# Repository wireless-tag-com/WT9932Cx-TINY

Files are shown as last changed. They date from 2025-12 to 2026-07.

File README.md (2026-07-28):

# WT9932Cx-TINY Resources

> [!IMPORTANT]
> This repository is no longer actively maintained and is retained as an archive. Board support, examples, and future documentation are now maintained in [WT_BSP](https://github.com/Wireless-TAG-Maker/WT_BSP). The existing contents remain available for historical reference.

[中文](./README_zh.md)

This repository mainly stores resources related to WT9932C2-TINY, WT9932C3-TINY, WT9932C5-TINY, and WT9932C61-TINY.

You can refer to our official documentation:

[WT9932C2-TINY Wiki](https://wiki.wireless-tag.com/docs/en/WT9932C2-TINY/board_features.html)

[WT9932C3-TINY Wiki](https://wiki.wireless-tag.com/docs/en/WT9932C3-TINY/board_features.html)

[WT9932C5-TINY Wiki](https://wiki.wireless-tag.com/docs/en/WT9932C5-TINY/board_features.html)

[WT9932C61-TINY Wiki](https://wiki.wireless-tag.com/docs/en/WT9932C61-TINY/board_features.html)

## Folder Overview

```shell
.
├── hardware # Hardware resources: schematics, BOM, gerber, and component placement files
├── other # User guides, module datasheets, and other documentation
└── software # Software resources
```

1. hardware

The hardware is designed using Lichuang EDA, and the full project will be open-sourced later. Currently, schematics, Gerber files, and other resources are available.

2. other

This folder mainly provides module datasheets, 3D models, CAD dimension drawings, pin definitions, label files, and other resources.

3. software

This folder mainly includes the ESP-IDF blink example, MicroPython firmware, AT firmware, and other software resources.

The environment setup tutorials are available on the online wiki.

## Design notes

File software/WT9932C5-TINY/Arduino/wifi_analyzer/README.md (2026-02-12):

# ESP32-C5 Tiny WiFi Analyzer

## How to Compile and Run

1. Install [Arduino](https://www.arduino.cc/)
2. In `File -> Preferences -> Additional Boards Manager URLs`, add:  
   `https://jihulab.com/esp-mirror/espressif/arduino-esp32/-/raw/gh-pages/package_esp32_index_cn.json`
3. Restart Arduino and install the ESP32 board package  
   > Note: Select the board package authored by `Espressif Systems`
4. Connect the C5 Tiny and select the corresponding COM port in Arduino
5. Open the board selection menu, search for C5, and choose **ESP32C5 Dev Module**
6. Download [Arduino_GFX](https://github.com/moononournation/Arduino_GFX/releases/tag/v1.6.5), extract it, and move it to:  
   `C:\Users\<YourUsername>\Documents\Arduino\libraries`
7. Open `ESP32C5WiFiAnalyzer\ESP32C5WiFiAnalyzer.ino` and install the **U8g2** library in Arduino
8. Compile and upload the firmware to the ESP32C5 Tiny
9. Connect the LCD according to the table below:

   | LCD Pin | ESP32C5 TINY Pin |
   |----------|-------------------|
   | GND      | GND               |
   | VCC      | 3.3V              |
   | SCL      | IO0               |
   | SDA      | IO1               |
   | RES      | IO2               |
   | DC       | IO4               |
   | CS       | IO5               |
   | BLK      | IO6               |

## Result

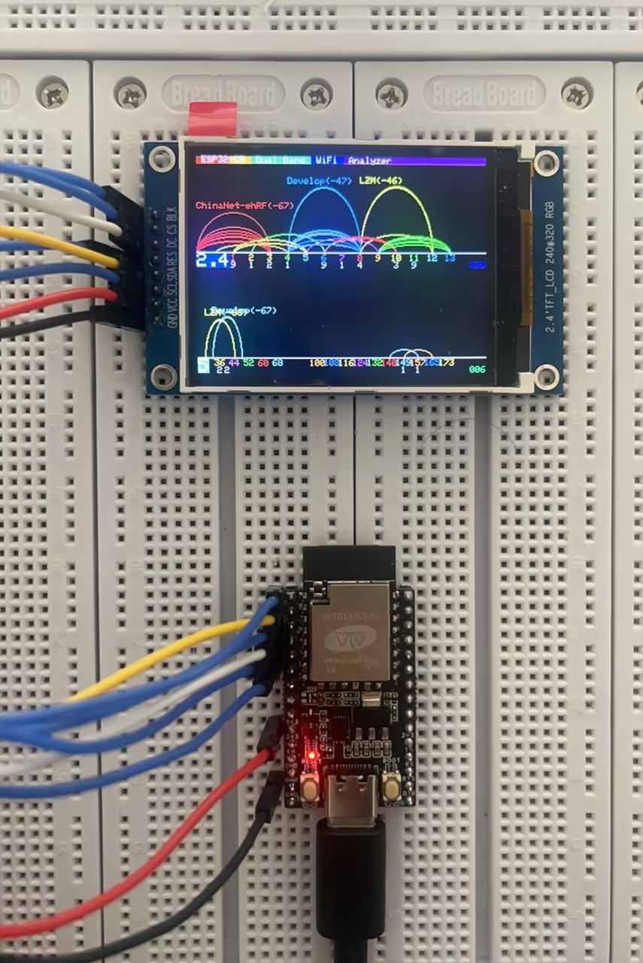
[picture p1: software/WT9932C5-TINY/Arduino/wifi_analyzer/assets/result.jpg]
result


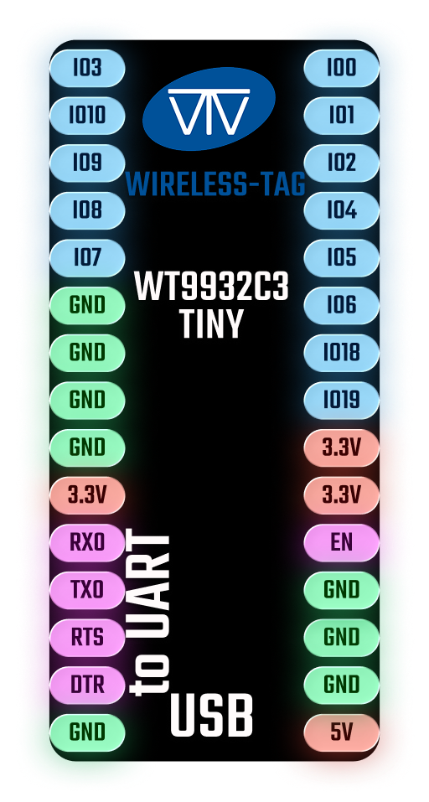
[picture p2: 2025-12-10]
other/WT9932C3-TINY/WT9932C3-TINY.png

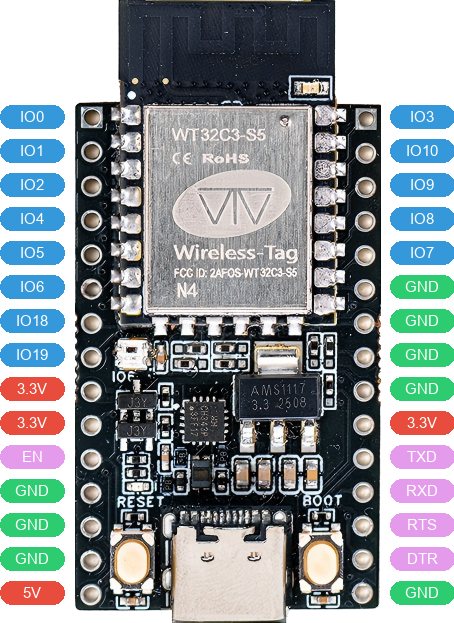
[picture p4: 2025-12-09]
other/WT9932C3-TINY/WT9932C3-TINY_引脚定义_V1.0.png

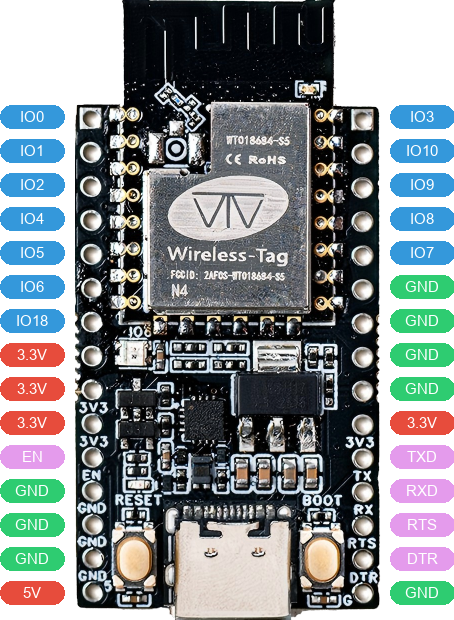
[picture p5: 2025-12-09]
other/WT9932C2-TINY/WT9932C2-TINY_引脚定义_V1.0.png

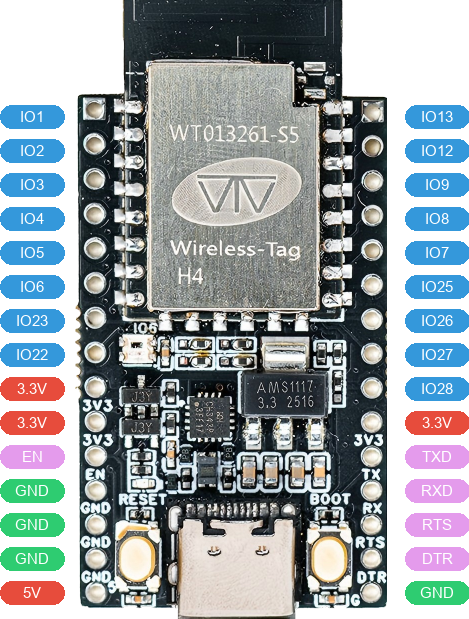
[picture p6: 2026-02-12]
other/WT9932C61-TINY/WT9932C61-TINY_引脚定义_V1.1.png

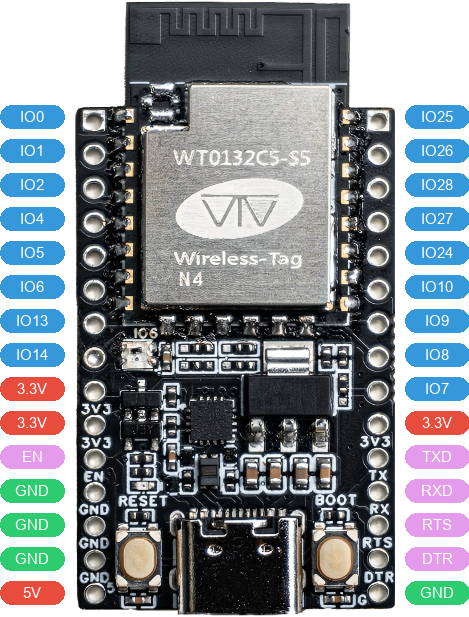
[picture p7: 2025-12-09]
other/WT9932C5-TINY/WT9932C5-TINY_引脚定义_V1.1.png

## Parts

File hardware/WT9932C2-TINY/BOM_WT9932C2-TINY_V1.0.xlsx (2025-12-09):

No. | Quantity | Comment | Designator | Footprint | Value | Manufacturer Part | Manufacturer | Supplier Part | Supplier | Tolerance | Overload Voltage (Max) | Output Voltage
1 | 4 | 100nF | C1,C2,C3,C11 | C0402 | 100nF | CC0402KRX7R7BB104 | YAGEO(国巨) | C60474 | LCSC | ±10%
2 | 3 | 10uF | C13,C15,C16 | C0603 | 10uF | CL10A106KP8NNNC | SAMSUNG(三星) | C19702 | LCSC | ±10%
3 | 1 | 100nF | C14 | C0603 | 100nF | CC0603KRX7R9BB104 | YAGEO(国巨) | C14663 | LCSC | ±10%
4 | 3 | H5VL10B | D1,D2,D3 | SOD-882_L1.0-W0.6-BI |  | H5VL10B | 宏迦橙 | C7420372 | LCSC
5 | 2 | ZX-PZ2.54-1-15PZZ | J1,J2 | HDR-TH_15P-P2.54-V-M |  | ZX-PZ2.54-1-15PZZ | Megastar(兆星) | C7501269 | LCSC
6 | 1 | WS2812B-2020 | J3 | LED-SMD_4P-L2.0-W2.0-TL_WS2812B-2020 |  | WS2812B-2020 | worldsemi | C965555 | LCSC
7 | 1 | TYPE-C 16PIN 2MD(073) | J4 | USB-C-SMD_TYPE-C-6PIN-2MD-073 |  | TYPE-C 16PIN 2MD(073) | SHOU HAN(首韩) | C2765186 | LCSC
8 | 2 | SKRPACE010 | J5,J6 | KEY-SMD_4P-L4.2-W3.2-P2.20-LS4.6 |  | SKRPACE010 | ALPSALPINE(阿尔卑斯阿尔派) | C139797 | LCSC
9 | 1 | SDCW2012C-2-900TF | L1 | FILTER-SMD_4P-L2.0-W1.3-BL |  | SDCW2012C-2-900TF | Sunlord(顺络) | C152717 | LCSC
10 | 1 | TZ-P2-0402RTIA1-0.45T | LED2 | LED0402-RD_RED |  | TZ-P2-0402RTIA1-0.45T | TUOZHAN(拓展光电) | C779449 | LCSC
11 | 2 | S8050 | Q1,Q2 | SOT-23-3_L2.9-W1.3-P1.90-LS2.3-BR |  | S8050 | 宏嘉诚 | C20069125 | LCSC
12 | 2 | 5.1kΩ | R1,R3 | R0402 | 5.1kΩ | 0402WGF5101TCE | UNI-ROYAL(厚声) | C25905 | LCSC | ±1% | 50V
13 | 7 | 10kΩ | R2,R4,R20,R24,R26,R27,R28 | R0402 | 10kΩ | 0402WGF1002TCE | UNI-ROYAL(厚声) | C25744 | LCSC | ±1% | 50V
14 | 6 | 0Ω | R13,R16,R17,R18,R19,R21 | R0402 | 0Ω | 0402WGF0000TCE | UNI-ROYAL(厚声) | C17168 | LCSC | ±1% | 50V
15 | 1 | CH343P | U2 | TQFN-16_L3.0-W3.0-P0.50-BL-EP1.7 |  | CH343P | WCH(南京沁恒) | C2846043 | LCSC
16 | 1 | AMS1117-3.3 | U5 | SOT-223-3_L6.5-W3.4-P2.30-LS7.0-BR |  | AMS1117-3.3 | AMS | C6186 | LCSC |  |  | 3.3V
17 | 1 | WT018684-S5 | U6 | WT0132Cx-S5

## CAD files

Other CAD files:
other/WT9932C2-TINY/WT9932C2-TINY_CAD_V1.0.DWG
other/WT9932C3-TINY/WT9932C3-TINY_CAD_V1.0.DWG
other/WT9932C5-TINY/WT9932C5-TINY_CAD_V1.0.DWG
other/WT9932C61-TINY/WT9932C61-TINY_CAD_V1.0.DWG

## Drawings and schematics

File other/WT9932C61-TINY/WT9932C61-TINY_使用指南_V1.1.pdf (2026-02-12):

# WT9932C61 TINY 使用指南

## WT9932C61 TINY 用户使用手册

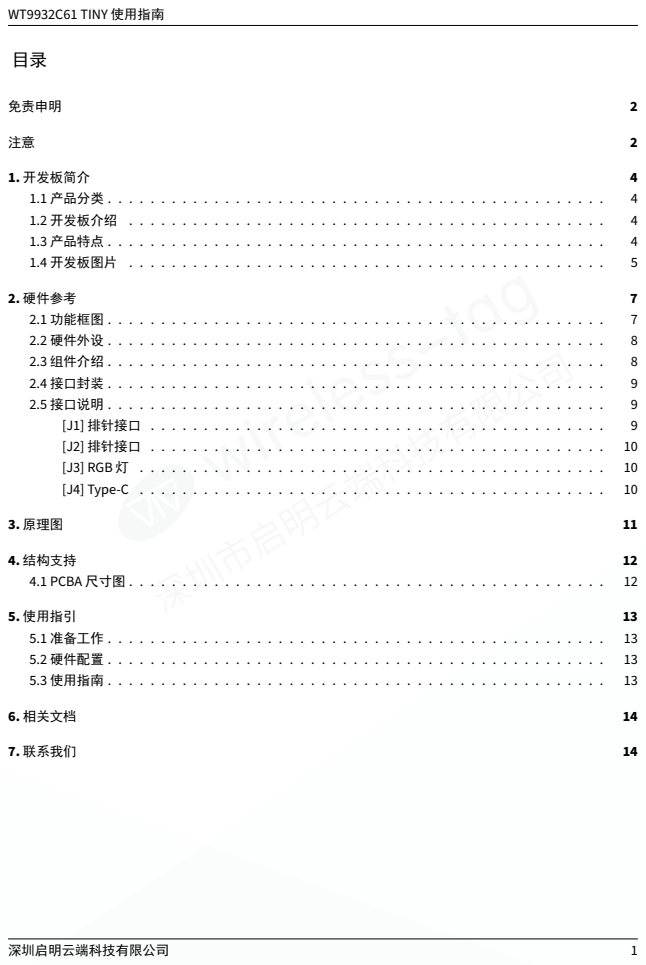
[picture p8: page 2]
WT9932C61 TINY 使用指南; 免责申明; 1. 开发板简介; 2. 硬件参考; 3. 原理图; 4. 结构支持; 5. 使用指引; 6. 相关文档; 7. 联系我们; 深圳启明云端科技有限公司

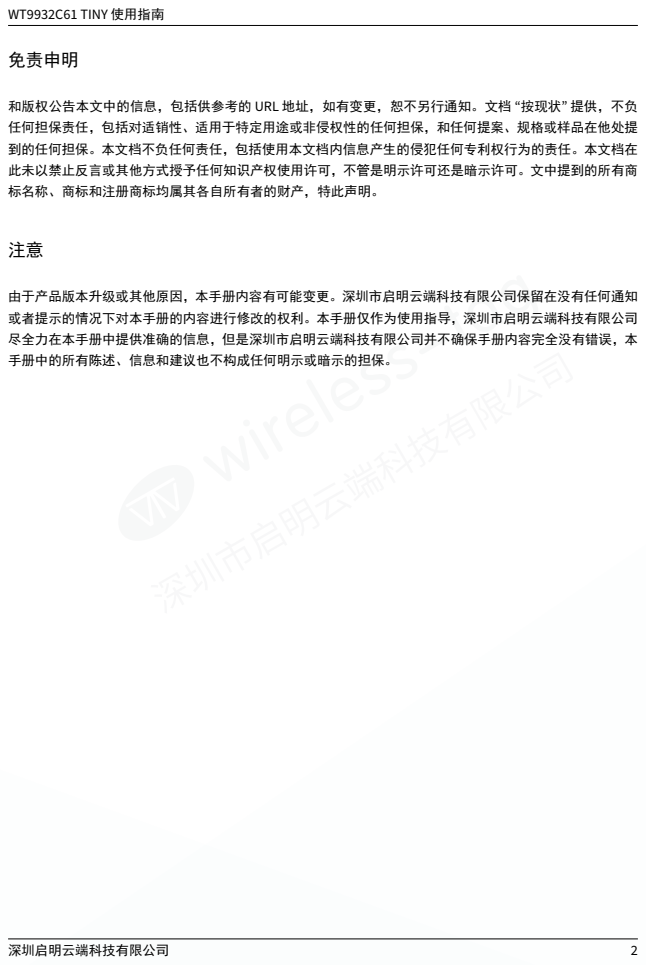
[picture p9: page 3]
免责申明

和版权公告本文中的信息，包括供参考的 URL 地址，如有变更，恕不另行通知。文档 “按现状” 提供，不负
任何担保责任，包括对适销性、适用于特定用途或非侵权性的任何担保，和任何提案、规格或样品在他处提
到的任何担保。本文档不负任何责任，包括使用本文档内信息产生的侵犯任何专利权行为的责任。本文档在
此未以禁止反言或其他方式授予任何知识产权使用许可，不管是明示许可还是暗示许可。文中提到的所有商
标名称、商标和注册商标均属其各自所有者的财产，特此声明。

由于产品版本升级或其他原因，本手册内容有可能变更。深圳市启明云端科技有限公司保留在没有任何通知
或者提示的情况下对本手册的内容进行修改的权利。本手册仅作为使用指导，深圳市启明云端科技有限公司
尽全力在本手册中提供准确的信息，但是深圳市启明云端科技有限公司并不确保手册内容完全没有错误，本
手册中的所有陈述、信息和建议也不构成任何明示或暗示的担保。

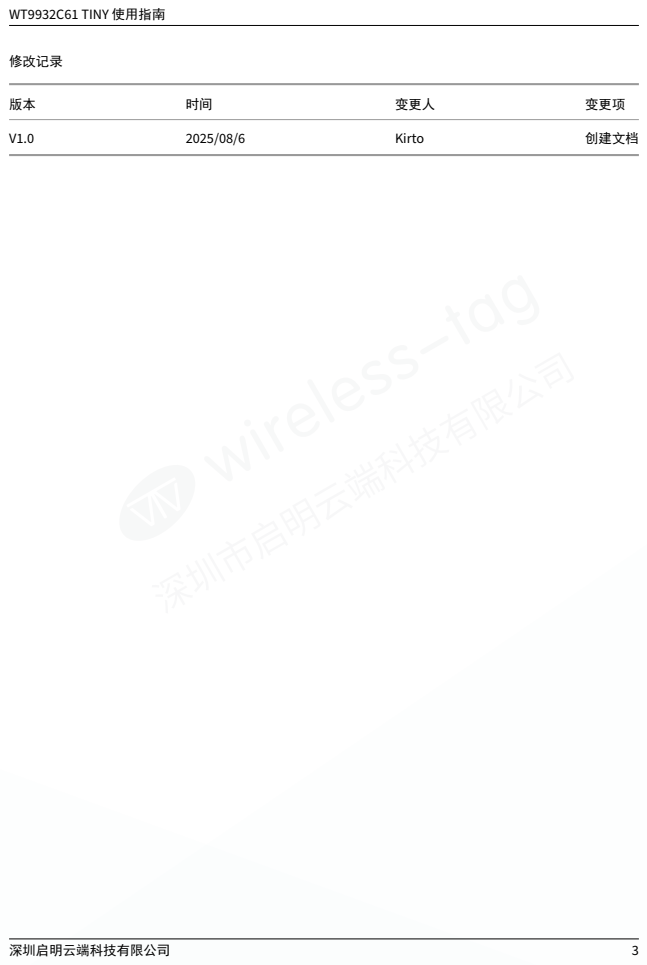
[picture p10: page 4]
修改记录; 变更人; 变更项; Kirto; 创建文档

### 1. 开发板简介

### 1.1 产品分类

### 1.2 开发板介绍

WT9932C61‑TINY 是一款专为轻量化物联网开发设计的迷你开发板，核心基于乐鑫 ESP32‑C61 芯片，搭载启 明云端 WT0132C61‑S5 模组，整体尺寸仅 23×38mm，在极小体积内实现了强劲性能与丰富功能的平衡。 开
发板主频高达 160MHz，依托 ESP32‑C61 升级的无线能力，支持 Wi‑Fi 6（802.11ax）、OFDMA、MU‑MIMO、
TWT 等新一代无线特性与蓝牙 5.3 双模通信，具备更强的安全机制（如 TEE、PSRAM 加密）和丰富外设（如 事件任务矩阵 ETM、模拟比较器），适用于更高性能和低功耗物联网场景。硬件设计上，不仅将所有引脚 全引出，支持面包板快速开发，还集成了 USB 转串口芯片，简化用户调试流程；同时板载 RGB 灯、EN 与 BOOT 功能按钮及电源指示灯，满足基础功能验证与状态监测需求；电源部分采用 LDO 设计，最大支持 1A 电流输出，保障外设稳定供电；此外，通过将 EN 引脚短接 GND，开发板可切换为 USB 转串口调试器，进一 步提升开发板功能性。

### 1.3 产品特点

1. 超小尺寸，高集成度 23×38mm 迷你尺寸，适配空间受限的场景（如小型智能设备、嵌入式模块），同 时集成模组、USB 转串口、板载灯 / 按钮，无需额外外接核心元件，开箱即可开发。
2. 强劲性能，双模无线 基于 ESP32‑C61 芯片，160MHz 主频保障数据处理效率，支持 WiFi 与蓝牙双模 通信，满足物联网设备的无线连接需求，适配智能家居、远程控制、数据传输等多场景。
3. 灵活开发，兼容便捷 所有引脚全引出，可直接插入面包板搭建原型，兼容各类传感器、执行器等外设； 支持板载 USB 转串口，无需额外购买串口模块，降低开发门槛。
4. 多功能调试，一物两用 板载 EN（使能）与 BOOT（启动）按钮，方便进入下载模式；通过 EN 短接 GND 可切换为 USB 转串口调试器，可用于其他设备的串口调试，提升硬件复用率。
5. 稳定供电，状态可视 LDO 电源设计最大支持 1A 电流输出，为外设提供稳定供电；板载电源指示灯实 时显示供电状态，RGB 灯可用于功能验证、状态指示（如网络连接、数据传输），直观便捷。

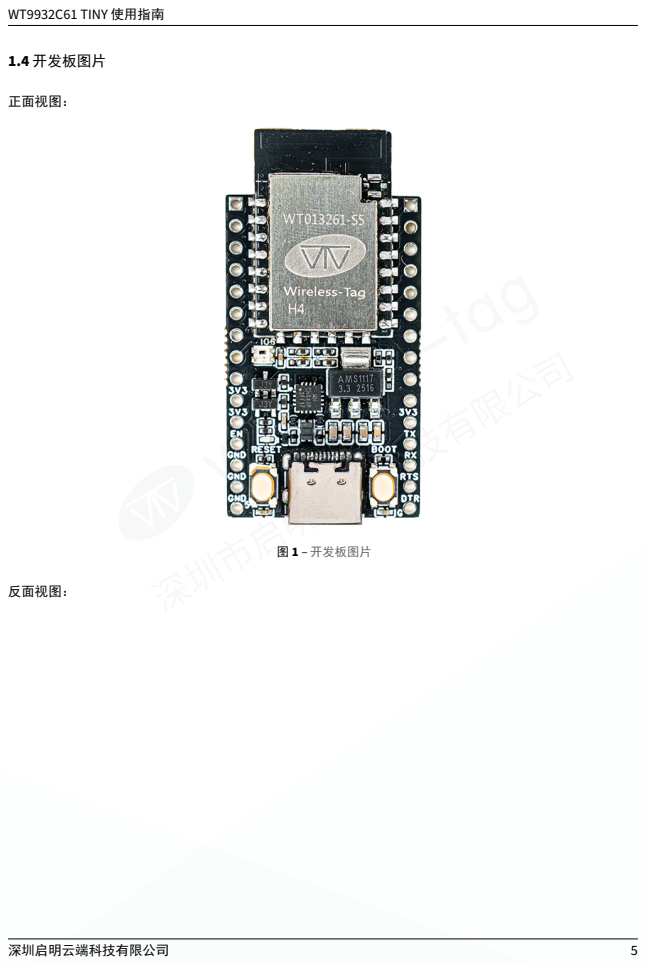
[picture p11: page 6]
1.4 开发板图片; 正面视图：; 图 1 – 开发板图片; 反面视图：

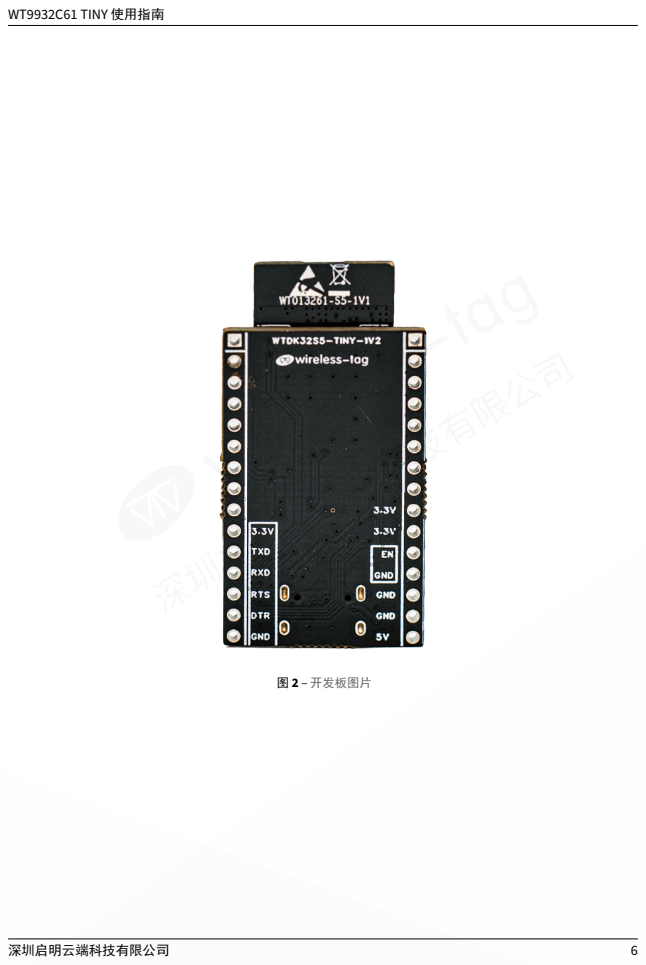
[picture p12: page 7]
图 2 – 开发板图片

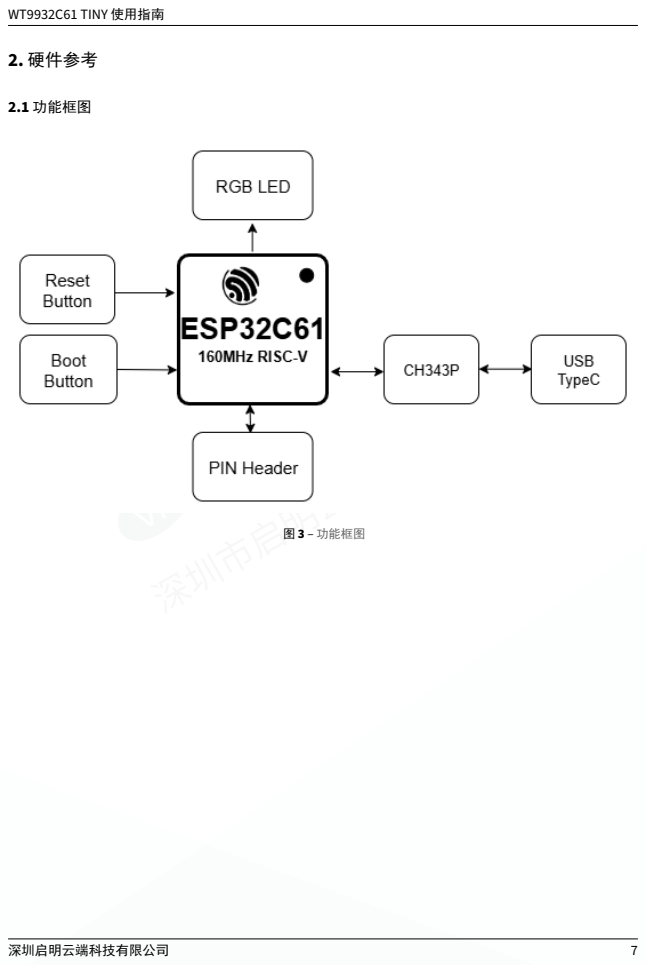
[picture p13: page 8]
2. 硬件参考; 2.1 功能框图; 图 3 – 功能框图

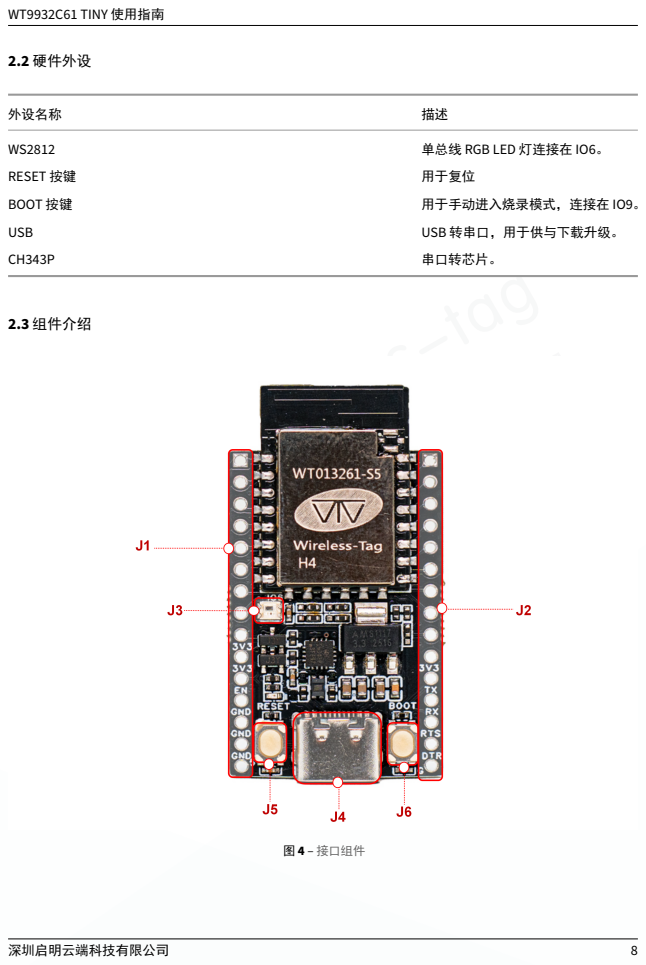
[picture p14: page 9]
2.2 硬件外设; 外设名称; 单总线 RGB LED 灯连接在 IO6。; RESET 按键; 用于复位; BOOT 按键; 用于手动进入烧录模式，连接在 IO9。; USB; USB 转串口，用于供与下载升级。; 串口转芯片。; 2.3 组件介绍; 图 4 – 接口组件

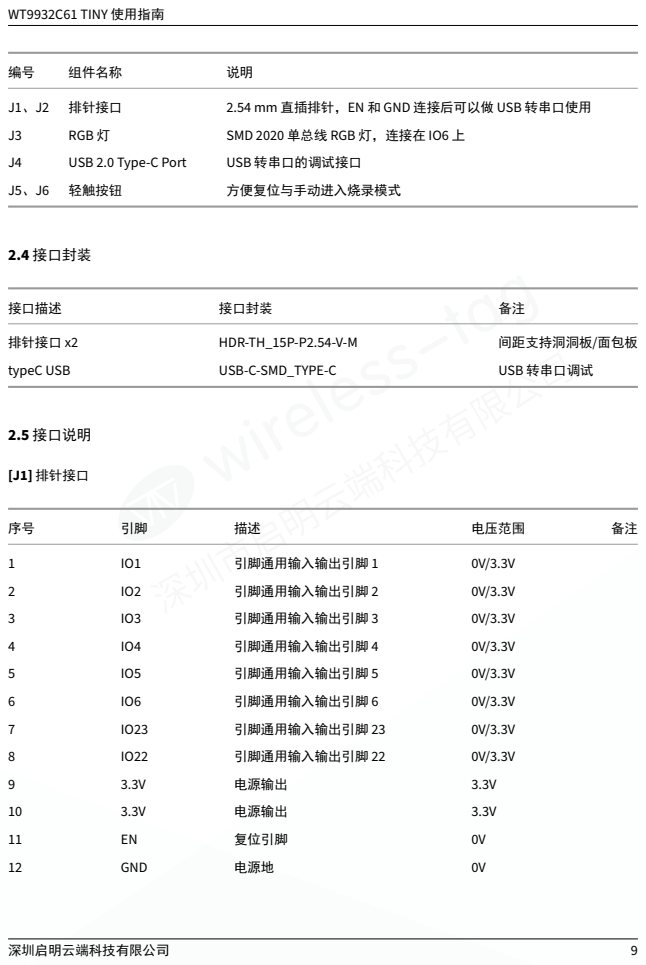
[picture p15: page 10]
组件名称; J1、J2 排针接口; 2.54 mm 直插排针，EN 和 GND 连接后可以做 USB 转串口使用; RGB 灯; SMD 2020 单总线 RGB 灯，连接在 IO6 上; USB 2.0 Type‑C Port; USB 转串口的调试接口; J5、J6 轻触按钮; 方便复位与手动进入烧录模式; 2.4 接口封装; 接口描述; 接口封装; 排针接口 x2; HDR‑TH_15P‑P2.54‑V‑M; 间距支持洞洞板/面包板; typeC USB; USB‑C‑SMD_TYPE‑C; USB 转串口调试; 2.5 接口说明; [J1] 排针接口; 电压范围; 引脚通用输入输出引脚 1; 引脚通用输入输出引脚 2; 引脚通用输入输出引脚 3; 引脚通用输入输出引脚 4; 引脚通用输入输出引脚 5; 引脚通用输入输出引脚 6; 引脚通用输入输出引脚 23; IO22 3.3V 3.3V EN GND; 引脚通用输入输出引脚 22; 电源输出; 复位引脚; 电源地

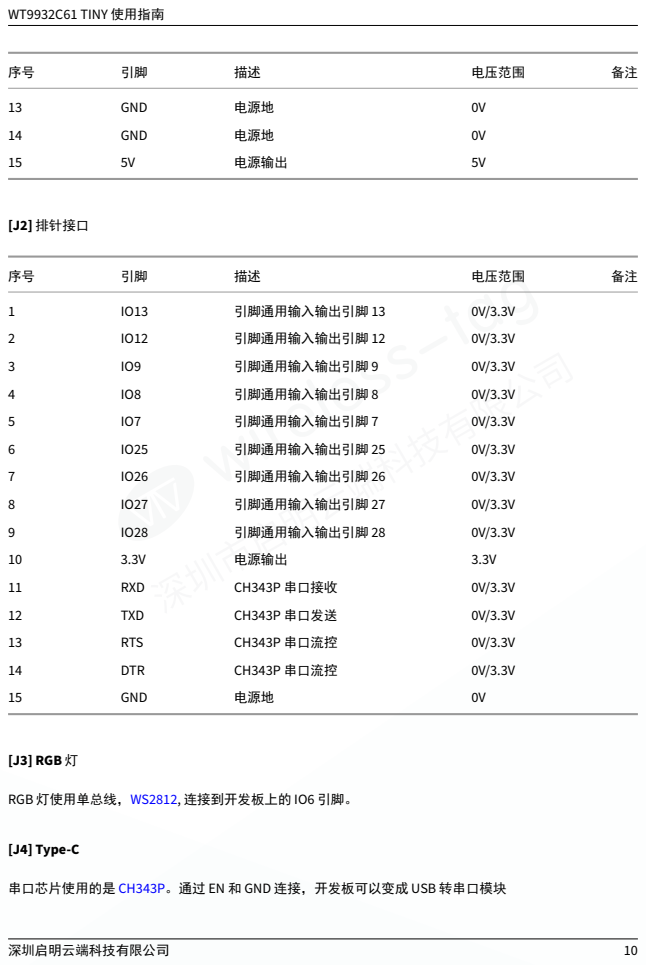
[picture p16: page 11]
电压范围; GND; 电源地; 电源输出; [J2] 排针接口; 引脚通用输入输出引脚 13; 引脚通用输入输出引脚 12; 引脚通用输入输出引脚 9; 引脚通用输入输出引脚 8; 引脚通用输入输出引脚 7; 引脚通用输入输出引脚 25; 引脚通用输入输出引脚 26; 引脚通用输入输出引脚 27; CH343P 串口接收; CH343P 串口发送; CH343P 串口流控; 引脚通用输入输出引脚 28; IO28 3.3V RXD TXD RTS DTR; [J3] RGB 灯; [J4] Type‑C

RGB 灯使用单总线，WS2812, (https://atta.szlcsc.com/upload/public/pdf/source/20241202/DEE3FC615B8AD87F3BB1718ACD77EDECD.pdf) 连接到开发板上的 IO6 引脚。

串口芯片使用的是 CH343P。通过 (https://atta.szlcsc.com/upload/public/pdf/source/20250526/E5D5661F81329277E82D637D359EA112.pdf) EN 和 GND 连接，开发板可以变成 USB 转串口模块

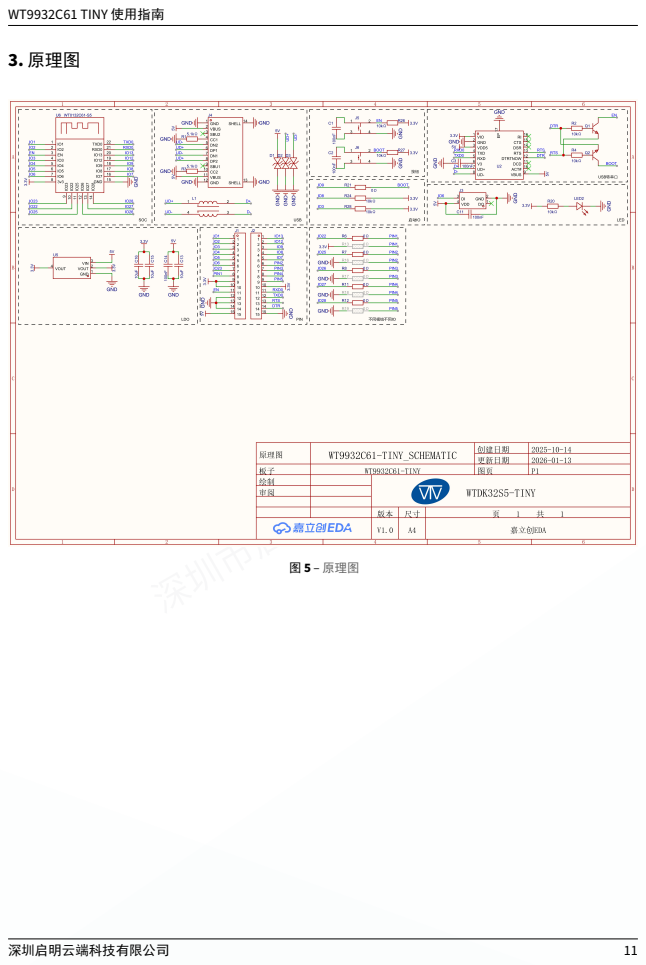
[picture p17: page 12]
3. 原理图; 图 5 – 原理图

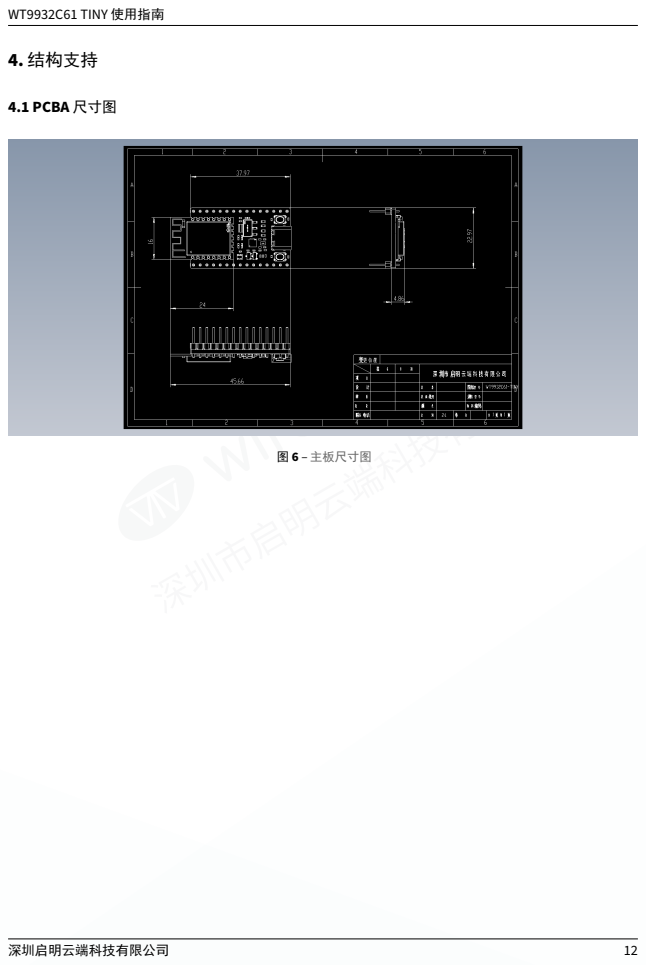
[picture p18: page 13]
4. 结构支持; 4.1 PCBA 尺寸图; 图 6 – 主板尺寸图

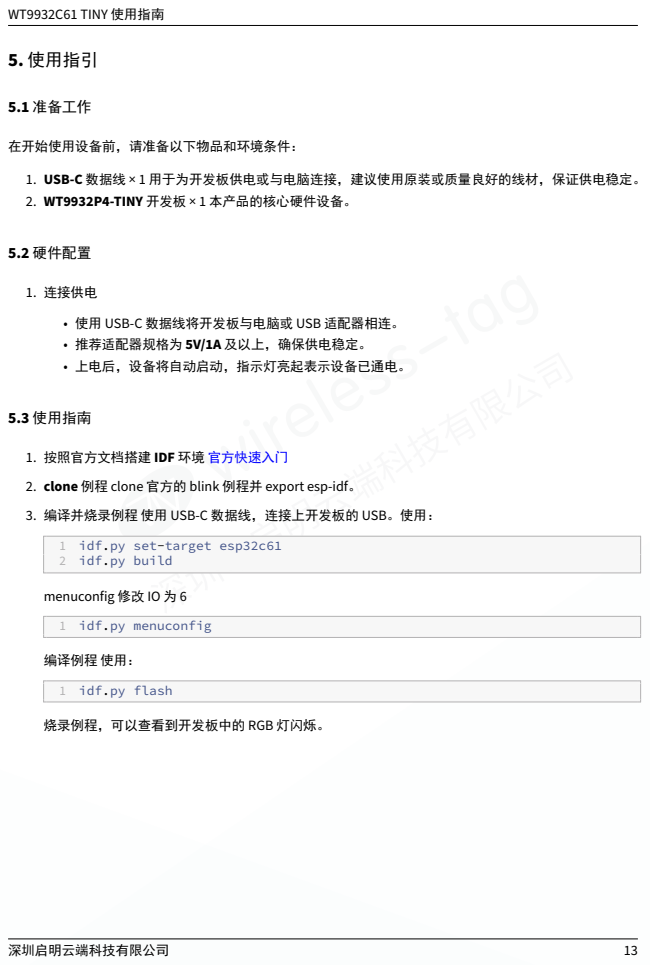
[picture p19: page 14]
5. 使用指引; 5.1 准备工作; 在开始使用设备前，请准备以下物品和环境条件：; 5.2 硬件配置; 1. 连接供电; 5.3 使用指南; 编译例程 使用：

1. USB‑C 数据线 × 1 用于为开发板供电或与电脑连接，建议使用原装或质量良好的线材，保证供电稳定。
2. WT9932P4‑TINY 开发板 × 1 本产品的核心硬件设备。

• 使用 USB‑C 数据线将开发板与电脑或 USB 适配器相连。
• 推荐适配器规格为 5V/1A 及以上，确保供电稳定。
• 上电后，设备将自动启动，指示灯亮起表示设备已通电。

1. 按照官方文档搭建 IDF 环境 官方快速入门 (https://docs.espressif.com/projects/esp-idf/zh_CN/v5.5.1/esp32c61/get-started/index.html)
2. clone 例程 clone 官方的 blink 例程并 export esp‑idf。

3. 编译并烧录例程 使用 USB‑C 数据线，连接上开发板的 USB。使用：

1 idf.py set-target esp32c61
2 idf.py build
menuconfig 修改 IO 为 6

1 idf.py menuconfig

1 idf.py flash

烧录例程，可以查看到开发板中的 RGB 灯闪烁。

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

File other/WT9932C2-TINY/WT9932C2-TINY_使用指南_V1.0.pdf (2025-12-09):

# WT9932C2 TINY 使用指南

## WT9932C2 TINY 用户使用手册

2025‑11‑12

WT9932C2 TINY 使用指南; 免责申明; 1. 开发板简介; 2. 硬件参考; 3. 原理图; 4. 结构支持; 5. 使用指引; 6. 相关文档; 7. 联系我们; 深圳启明云端科技有限公司 PD:Kirto

免责申明

和版权公告本文中的信息，包括供参考的 URL 地址，如有变更，恕不另行通知。文档 “按现状” 提供，不负
任何担保责任，包括对适销性、适用于特定用途或非侵权性的任何担保，和任何提案、规格或样品在他处提
到的任何担保。本文档不负任何责任，包括使用本文档内信息产生的侵犯任何专利权行为的责任。本文档在
此未以禁止反言或其他方式授予任何知识产权使用许可，不管是明示许可还是暗示许可。文中提到的所有商
标名称、商标和注册商标均属其各自所有者的财产，特此声明。

由于产品版本升级或其他原因，本手册内容有可能变更。深圳市启明云端科技有限公司保留在没有任何通知
或者提示的情况下对本手册的内容进行修改的权利。本手册仅作为使用指导，深圳市启明云端科技有限公司
尽全力在本手册中提供准确的信息，但是深圳市启明云端科技有限公司并不确保手册内容完全没有错误，本
手册中的所有陈述、信息和建议也不构成任何明示或暗示的担保。

修改记录; 变更人; 变更项; Kirto; 创建文档

### 1. 开发板简介

### 1.1 产品分类

### 1.2 开发板介绍

WT9932C2‑TINY 是一款专为轻量化物联网开发设计的迷你开发板，核心基于乐鑫 ESP32‑C2 芯片，搭载启明 云端 WT08684‑S5 模组，整体尺寸仅 23×38mm，在极小体积内实现了强劲性能与丰富功能的平衡。 开发板 主频高达 120MHz，支持蓝牙与 WiFi 双模无线通信，可无缝适配智能家居、低功耗物联网终端等场景；硬件 设计上，不仅将所有引脚全引出，支持面包板快速开发，还集成了 USB 转串口芯片，简化用户调试流程；同 时板载 RGB 灯、EN 与 BOOT 功能按钮及电源指示灯，满足基础功能验证与状态监测需求；电源部分采用 LDO 设计，最大支持 1A 电流输出，保障外设稳定供电；此外，通过将 EN 引脚短接 GND，开发板可切换为 USB 转串口调试器，进一步提升开发板功能性。

### 1.3 产品特点

1. 超小尺寸，高集成度 23×38mm 迷你尺寸，适配空间受限的场景（如小型智能设备、嵌入式模块），同 时集成模组、USB 转串口、板载灯 / 按钮，无需额外外接核心元件，开箱即可开发。
2. 强劲性能，双模无线 基于 ESP32‑C2 芯片，120MHz 主频保障数据处理效率，支持 WiFi 与蓝牙双模通 信，满足物联网设备的无线连接需求，适配智能家居、远程控制、数据传输等多场景。
3. 灵活开发，兼容便捷 所有引脚全引出，可直接插入面包板搭建原型，兼容各类传感器、执行器等外设； 支持板载 USB 转串口，无需额外购买串口模块，降低开发门槛。出厂自带 micropython，方便用户直 接使用脚本开发。
4. 多功能调试，一物两用 板载 EN（使能）与 BOOT（启动）按钮，方便进入下载模式；通过 EN 短接 GND 可切换为 USB 转串口调试器，可用于其他设备的串口调试，提升硬件复用率。
5. 稳定供电，状态可视 LDO 电源设计最大支持 1A 电流输出，为外设提供稳定供电；板载电源指示灯实 时显示供电状态，RGB 灯可用于功能验证、状态指示（如网络连接、数据传输），直观便捷。

1.4 开发板图片; 正面视图：; 图 1 – 开发板图片; 反面视图：

图 2 – 开发板图片

2. 硬件参考; 2.1 功能框图; 图 3 – 功能框图

2.2 硬件外设; 外设名称; 单总线 RGB LED 灯连接在 IO6。; RESET 按键; 用于复位; BOOT 按键; 用于手动进入烧录模式，连接在 IO9。; USB; USB 转串口，用于供与下载升级。; 串口转芯片。; 2.3 组件介绍; 图 4 – 接口组件

组件名称; J1、J2 排针接口; 2.54 mm 直插排针，EN 和 GND 连接后可以做 USB 转串口使用; RGB 灯; SMD 2020 单总线 RGB 灯，连接在 IO6 上; USB 2.0 Type‑C Port; USB 转串口的调试接口; J5、J6 轻触按钮; 方便复位与手动进入烧录模式; 2.4 接口封装; 接口描述; 接口封装; 排针接口 x2; HDR‑TH_15P‑P2.54‑V‑M; 间距支持洞洞板/面包板; typeC USB; USB‑C‑SMD_TYPE‑C; USB 转串口调试; 2.5 接口说明; [J1] 排针接口; 电压范围; 引脚通用输入输出引脚 0; 引脚通用输入输出引脚 1; 引脚通用输入输出引脚 2; 引脚通用输入输出引脚 4; 引脚通用输入输出引脚 5; 引脚通用输入输出引脚 6; 引脚通用输入输出引脚 18; 电源输出; 复位引脚; GND; 电源地

电压范围; GND; 电源地; 电源输出; [J2] 排针接口; 引脚通用输入输出引脚 3; 引脚通用输入输出引脚 10; 引脚通用输入输出引脚 9; 引脚通用输入输出引脚 8; 引脚通用输入输出引脚 7; RXD; CH343P 串口接收; TXD; CH343P 串口发送; RTS; CH343P 串口流控; DTR; [J3] RGB 灯; [J4] Type‑C

RGB 灯使用单总线，WS2812, (https://atta.szlcsc.com/upload/public/pdf/source/20241202/DEE3FC25B8AD87F3BB1718ACD77EDECD.pdf) 连接到开发板上的 IO6 引脚。

串口芯片使用的是 CH343P。通过 (https://atta.szlcsc.com/upload/public/pdf/source/20250526/E5D5661F81329277E82D637D359EA112.pdf) EN 和 GND 连接，开发板可以变成 USB 转串口模块

3. 原理图

图 5 – 原理图; 4. 结构支持; 4.1 PCBA 尺寸图

图 6 – 主板尺寸图; 5. 使用指引; 5.1 准备工作; 在开始使用设备前，请准备以下物品和环境条件：; 5.2 硬件配置; 1. 连接供电; 5.3 使用指南

1. USB‑C 数据线 × 1 用于为开发板供电或与电脑连接，建议使用原装或质量良好的线材，保证供电稳定。
2. WT9932C2‑TINY 开发板 × 1 本产品的核心硬件设备。
3. 串口调试器 用于调试查看日志。

• 使用 USB‑C 数据线将开发板与电脑或 USB 适配器相连。
• 上电后，设备将自动启动，指示灯亮起表示设备已通电。

1. 连接好开发板和电脑 通过 USB‑C 线连接电脑。> 注意：部分电脑可能需要安装驱动 (https://www.wch.cn/downloads/CH343SER_EXE.html)
2. 打开串口调试器 找到自己的串口号，设置波特率为 115200。即可打开交互式命令行。产品出厂自
带micropython，可以通过交互式命令行发送脚本语法 (https://docs.micropython.org/en/latest/)


注意：本模组采用 26 MHz 的晶振，在使用 esp‑idf 的时，需要切换 menuconfig 中 Component config
–> Hardware Settings –> Main XTAL Config 更改成 26 MHz。否则会出现乱码的情况。

6. 相关文档; 文档名称; WT9932C2‑ TINY 设备; 使用指南; WT9932C2‑TINY ‑设备使用指南; ESP32‑C2 idf 在线文; ESP‑IDF 编; 程指南与 API 说明; ESP32‑C2; 技术参考手; 芯片参数参; micropython; 在线文档; 7. 联系我们; 图 7 – Wireless‑Tag_qrcode

https://docs.espressif.com/projects/esp‑idf/zh_CN/v5.4.2/esp32c2/get‑
started/index.html (https://docs.espressif.com/projects/esp-idf/zh_CN/v5.4.2/esp32c2/get-started/index.html)

https://www.espressif.com.cn/sites/default/files/documentation/esp8684_d
atasheet_cn.pdf (https://www.espressif.com.cn/sites/default/files/documentation/esp8684_datasheet_cn.pdf)

https://docs.micropython.org/en/latest/

• 官方网址：https://www.wireless‑tag.com/ (https://www.wireless-tag.com/)
• 淘宝连接：https://shop538225597.taobao.com/
• 销售邮箱：sales@wireless‑tag.com (https://www.wireless-tag.com/)
• 技术支持邮箱：technical@wireless‑tag.com (https://www.wireless-tag.com/)
• 联系电话：18122057087

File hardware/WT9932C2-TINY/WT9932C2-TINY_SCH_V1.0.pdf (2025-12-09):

## C1 100nF

## C2 100nF


ACT# 10 DCD 11 DTRTNOW 12 RTS 13 DSR 14 CTS 15 RI 16 EP ¹⁷

原理图 | WT9932C2-TINY_SCHEMATIC | 创建日期 | 2025-07-27

更新日期 | 2025-10-24

板子 | WT9932C2-TINY | 图页 | P1
绘制 | Kirto | WTDK32S5-TINY
审阅

Kirto

V1.0 | A4 | 嘉立创EDA

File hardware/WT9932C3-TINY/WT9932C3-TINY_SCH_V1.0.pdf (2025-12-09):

## C1 100nF

## C2 100nF


ACT# 10 DCD 11 DTRTNOW 12 RTS 13 DSR 14 CTS 15 RI 16 EP ¹⁷

原理图 | WT9932C3-TINY_SCHEMATIC | 创建日期 | 2025-07-27

更新日期 | 2025-10-20

板子 | WT9932C3-TINY | 图页 | P1
绘制 | Kirto | WTDK32S5-TINY
审阅

Kirto

V1.0 | A4 | 嘉立创EDA

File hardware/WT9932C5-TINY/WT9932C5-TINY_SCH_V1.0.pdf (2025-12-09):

## C1 100nF

## C2 100nF


ACT# 10 DCD 11 DTRTNOW 12 RTS 13 DSR 14 CTS 15 RI 16 EP ¹⁷

原理图 | WT9932C5-TINY_SCHEMATIC | 创建日期 | 2025-07-27

更新日期 | 2025-10-20

板子 | WT9932C5-TINY | 图页 | P1
绘制 | Kirto | WTDK32S5-TINY
审阅

Kirto

V1.0 | A4 | 嘉立创EDA

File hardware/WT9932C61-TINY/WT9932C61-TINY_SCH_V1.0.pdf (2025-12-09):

## C1 100nF

## C2 100nF


ACT# 10 DCD 11 DTRTNOW 12 RTS 13 DSR 14 CTS 15 RI 16 EP ¹⁷

原理图 | WT9932C61-TINY_SCHEMATIC | 创建日期 | 2025-10-14

更新日期 | 2025-10-20

板子 | WT9932C61-TINY | 图页 | P1
绘制 | | WTDK32S5-TINY
审阅

V1.0 | A4 | 嘉立创EDA

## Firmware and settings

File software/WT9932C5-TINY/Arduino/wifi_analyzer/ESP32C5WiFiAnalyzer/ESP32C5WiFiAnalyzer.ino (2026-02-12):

/*******************************************************************************
 * ESP32-C5 WiFi Analyzer
 * Requires ESP32-C5 board
 ******************************************************************************/
#if CONFIG_SOC_WIFI_SUPPORT_5G

// POWER SAVING SETTING
#define SCAN_INTERVAL 3000
// #define SCAN_COUNT_SLEEP 5
// #define LCD_PWR_PIN 0
// #define LCD_PWR_PIN1 1
// #define LCD_PWR_PIN2 2
// #define LCD_PWR_PIN3 3

/*******************************************************************************
 * Start of Arduino_GFX setting
 *
 * Arduino_GFX try to find the settings depends on selected board in Arduino IDE
 * Or you can define the display dev kit not in the board list
 * Defalult pin list for non display dev kit:
 * ESP32-C5 various dev board  : CS: 23, DC: 24, RST: 25, BL: 26, SCK: 10, MOSI:  8, MISO: nil
 ******************************************************************************/
#include <Arduino_GFX_Library.h>

#define GFX_BL 6 // default backlight pin, you may replace DF_GFX_BL to actual backlight pin

/* More dev device declaration: https://github.com/moononournation/Arduino_GFX/wiki/Dev-Device-Declaration */
#if defined(DISPLAY_DEV_KIT)
Arduino_GFX *gfx = create_default_Arduino_GFX();
#else /* !defined(DISPLAY_DEV_KIT) */

/* More data bus class: https://github.com/moononournation/Arduino_GFX/wiki/Data-Bus-Class */
/* 自定义 SPI Bus */
Arduino_DataBus *bus = new Arduino_ESP32SPI(
    4,
    5,
    0,
    1,
    -1,
    FSPI
);

/* ST7789 屏 */
Arduino_GFX *gfx = new Arduino_ST7789(
    bus,
    2,
    1,      // rotation
    false   // IPS
);


#endif /* !defined(DISPLAY_DEV_KIT) */
/*******************************************************************************
 * End of Arduino_GFX setting
 ******************************************************************************/

#include <WiFi.h>

int16_t w, h, banner_text_size, banner_height, graph24_baseline, graph50_baseline, graph_baseline, graph_height, channel24_width, channel50_width, signal_width;

// RSSI RANGE
#define RSSI_CEILING -30
#define RSSI_SHOW_SSID -70
#define RSSI_FLOOR -100

// Channel legend mapping
uint8_t channel_legend[] = {
    1, 2, 3, 4, 5, 6, 7,     // 0-6:     1,  2,  3,  4,  5,  6,  7,
    8, 9, 10, 11, 12, 13, 0, // 7-13:    8,  9, 10, 11, 12, 13, 14,
    0, 0, 36, 0, 0, 0, 44,   // 14-20:  32, 34, 36, 38, 40, 42, 44,
    0, 0, 0, 52, 0, 0, 0,    // 21-27:  46, 48, 50, 52, 54, 56, 58,
    60, 0, 0, 0, 68, 0, 0,   // 28-34:  60, 62, 64,N/A, 68,N/A,N/A,
    0, 0, 0, 0, 0, 0, 0,     // 35-41: N/A,N/A,N/A,N/A,N/A,N/A, 96,
    0, 100, 0, 0, 0, 108, 0, // 42-48: N/A,100,102,104,106,108,110,
    0, 0, 116, 0, 0, 0, 124, // 49-55: 112,114,116,118,120,122,124,
    0, 0, 0, 132, 0, 0, 0,   // 56-62: 126,128,N/A,132,134,136,138,
    140, 0, 0, 0, 149, 0, 0, // 63-69: 140,142,144,N/A,149,151,153,
    0, 157, 0, 0, 0, 165, 0, // 70-76: 155,157,159,161,163,165,167,
    0, 0, 173, 0, 0, 0};     // 77-82: 169,171,173,175,177,N/A

// Channel color mapping
uint16_t channel_color[] = {
    RGB565_RED, RGB565_ORANGE, RGB565_YELLOW, RGB565_LIME, RGB565_CYAN, RGB565_DODGERBLUE, RGB565_MAGENTA,
    RGB565_RED, RGB565_ORANGE, RGB565_YELLOW, RGB565_LIME, RGB565_CYAN, RGB565_DODGERBLUE, RGB565_MAGENTA,
    RGB565_RED, RGB565_ORANGE, RGB565_YELLOW, RGB565_LIME, RGB565_CYAN, RGB565_DODGERBLUE, RGB565_MAGENTA,
    RGB565_RED, RGB565_ORANGE, RGB565_YELLOW, RGB565_LIME, RGB565_CYAN, RGB565_DODGERBLUE, RGB565_MAGENTA,
    RGB565_RED, RGB565_ORANGE, RGB565_YELLOW, RGB565_WHITE, RGB565_CYAN, RGB565_WHITE, RGB565_WHITE,
    RGB565_WHITE, RGB565_WHITE, RGB565_WHITE, RGB565_WHITE, RGB565_WHITE, RGB565_WHITE, RGB565_MAGENTA,
    RGB565_WHITE, RGB565_ORANGE, RGB565_YELLOW, RGB565_LIME, RGB565_CYAN, RGB565_DODGERBLUE, RGB565_MAGENTA,
    RGB565_RED, RGB565_ORANGE, RGB565_YELLOW, RGB565_LIME, RGB565_CYAN, RGB565_DODGERBLUE, RGB565_MAGENTA,
    RGB565_RED, RGB565_ORANGE, RGB565_WHITE, RGB565_LIME, RGB565_CYAN, RGB565_DODGERBLUE, RGB565_MAGENTA,
    RGB565_RED, RGB565_ORANGE, RGB565_YELLOW, RGB565_WHITE, RGB565_CYAN, RGB565_DODGERBLUE, RGB565_MAGENTA,
    RGB565_RED, RGB565_ORANGE, RGB565_YELLOW, RGB565_LIME, RGB565_CYAN, RGB565_DODGERBLUE, RGB565_MAGENTA,
    RGB565_RED, RGB565_ORANGE, RGB565_YELLOW, RGB565_LIME, RGB565_CYAN, RGB565_WHITE};

uint8_t scan_count = 0;

uint16_t channelIdx(int channel)
{
  if (channel <= 14) // 2.4 GHz, channel 1-14
  {
    return channel - 1;
  }
  if (channel <= 68) // 5 GHz, channel 32 - 64
  {
    return 14 + ((channel - 32) / 2);
  }
  if (channel <= 144) // channel 96 - 144
  {
    return 41 + ((channel - 96) / 2);
  }
  if (channel <= 177) // channel 149 - 177
  {
    return 67 + ((channel - 149) / 2);
  }
  return 82;
}

void setup()
{
#if defined(LCD_PWR_PIN)
  pinMode(LCD_PWR_PIN, OUTPUT);    // sets the pin as output
  digitalWrite(LCD_PWR_PIN, HIGH); // power on
#endif
#if defined(LCD_PWR_PIN)
  pinMode(LCD_PWR_PIN1, OUTPUT);    // sets the pin as output
  pinMode(LCD_PWR_PIN2, OUTPUT);    // sets the pin as output
  pinMode(LCD_PWR_PIN3, OUTPUT);    // sets the pin as output
  digitalWrite(LCD_PWR_PIN1, HIGH); // power on
  digitalWrite(LCD_PWR_PIN2, HIGH); // power on
  digitalWrite(LCD_PWR_PIN3, HIGH); // power on
#endif

#ifdef DEV_DEVICE_INIT
  DEV_DEVICE_INIT();
#endif

  Serial.begin(115200);
  // Serial.setDebugOutput(true);
  // while(!Serial);
  Serial.println("Arduino_GFX ESP32-C5 WiFi Analyzer UTF8 example");

  // Enable Station Interface
  WiFi.STA.begin();

  // Init Display
  if (!gfx->begin())
  {
    Serial.println("gfx->begin() failed!");
  }
  gfx->fillScreen(RGB565_BLACK);

#ifdef GFX_BL
  pinMode(GFX_BL, OUTPUT);
  digitalWrite(GFX_BL, HIGH);
#endif

  w = gfx->width();
  h = gfx->height();
  banner_text_size = (w < 444) ? 1 : 2;
  banner_height = (banner_text_size * 8) + 2;
  graph_height = ((h - banner_height) / 2) - 20; // minus 2 text lines
  graph24_baseline = banner_height + graph_height;
  graph50_baseline = graph24_baseline + 20 + graph_height;
  channel24_width = w / (14 + 2);
  channel50_width = w / (sizeof(channel_legend) - 14 + 4);

  // init banner
  gfx->fillRect(0, 0, w, banner_text_size * 8, RGB565_PURPLE);
  gfx->setTextSize(banner_text_size);
  gfx->setCursor(0, 0);
  gfx->setTextColor(RGB565_WHITE, RGB565_RED);
  gfx->print(" ESP32");
  gfx->setTextColor(RGB565_WHITE, RGB565_DARKORANGE);
  gfx->print("-C5 ");
  gfx->setTextColor(RGB565_WHITE, RGB565_LIMEGREEN);
  gfx->print(" Dual Band ");
  gfx->setTextColor(RGB565_WHITE, RGB565_MEDIUMBLUE);
  gfx->print(" WiFi ");
  gfx->setTextColor(RGB565_WHITE, RGB565_PURPLE);
  gfx->print(" Analyzer");
  gfx->setTextSize(1);

#ifdef CANVAS
  gfx->flush();
#endif
}

bool matchBssidPrefix(uint8_t *a, uint8_t *b)
{
  for (uint8_t i = 0; i < 5; i++)
  { // only compare first 5 bytes
    if (a[i] != b[i])
    {
      return false;
    }
  }
  return true;
}

void loop()
{
  uint16_t ap24_count = 0, ap50_count = 0;
  uint8_t ap_count_list[sizeof(channel_legend)];
  int32_t peak_list[sizeof(channel_legend)];
  int16_t peak_id_list[sizeof(channel_legend)];
  int32_t channel;
  int16_t idx;
  int32_t rssi;
  uint8_t *bssid;
  String ssid;
  uint16_t color;
  int16_t height, offset, text_width;

  // init array value
  for (int i = 0; i < sizeof(channel_legend); ++i)
  {
    ap_count_list[i] = 0;
    peak_list[i] = RSSI_FLOOR;
    peak_id_list[i] = -1;
  }

  WiFi.setBandMode((scan_count < 1) ? WIFI_BAND_MODE_2G_ONLY : WIFI_BAND_MODE_AUTO);
  // WiFi.setBandMode(WIFI_BAND_MODE_5G_ONLY);

  // WiFi.scanNetworks will return the number of networks found
  int n = WiFi.scanNetworks(false /* async */, true /* show_hidden */, false /* passive */, (scan_count < 2) ? 30 : 300 /* max_ms_per_chan */);

  // clear old graph
  gfx->fillRect(0, banner_height, w, h - banner_height, RGB565_BLACK);

  if (n == 0)
  {
    gfx->setTextColor(RGB565_WHITE);
    gfx->setCursor(0, banner_height);
    gfx->println("No networks found");
  }
  else
  {
    for (int i = 0; i < n; i++)
    {
      channel = WiFi.channel(i);
      idx = channelIdx(channel);
      rssi = WiFi.RSSI(i);
      bssid = WiFi.BSSID(i);
      ssid = WiFi.SSID(i);

      // channel peak stat, find peak ssid
      if (ssid.length() > 0)
      {
        if (peak_list[idx] < rssi)
        {
          peak_list[idx] = rssi;
          peak_id_list[idx] = i;
        }
      }

      // check signal come from same AP
      bool duplicate_SSID = false;
      for (int j = 0; j < i; j++)
      {
        if ((WiFi.channel(j) == channel) && matchBssidPrefix(WiFi.BSSID(j), bssid))
        {
          duplicate_SSID = true;
          break;
        }
      }

      if (!duplicate_SSID)
      {
        ap_count_list[idx]++;
        if (channel <= 14)
        {
          ap24_count++;
        }
        else
        {
          ap50_count++;
        }
      }
    }
    Serial.printf("ap24_count: %d, ap50_count: %d\n", ap24_count, ap50_count);

    // plot found WiFi info
    for (int i = 0; i < n; i++)
    {
      channel = WiFi.channel(i);
      idx = channelIdx(channel);
      rssi = WiFi.RSSI(i);
      color = channel_color[idx];
      height = constrain(map(rssi, RSSI_FLOOR, RSSI_CEILING, 1, graph_height), 1, graph_height);
      if (idx < 14)
      {
        graph_baseline = graph24_baseline;
        signal_width = channel24_width * 2;
        offset = (idx + 2) * channel24_width;
      }
      else
      {
        graph_baseline = graph50_baseline;
        signal_width = channel50_width * 4;
        offset = (idx - 14 + 4) * channel50_width;
      }

      // trim rssi with RSSI_FLOOR
      if (rssi < RSSI_FLOOR)
      {
        rssi = RSSI_FLOOR;
      }

      // plot chart
      // gfx->drawLine(offset, graph_baseline - height, offset - signal_width, graph_baseline + 1, color);
      // gfx->drawLine(offset, graph_baseline - height, offset + signal_width, graph_baseline + 1, color);
      gfx->startWrite();
      gfx->writeEllipseHelper(offset, graph_baseline + 1, signal_width, height, 0b0011, color);
      gfx->endWrite();

      if ((rssi >= RSSI_SHOW_SSID) && (i == peak_id_list[idx]))
      {
        // Print SSID, signal strengh and if not encrypted
        ssid = WiFi.SSID(i);
        if (ssid.length() == 0)
        {
          ssid = WiFi.BSSIDstr(i);
        }
        text_width = (ssid.length() + 6) * 6;
        if (text_width > w)
        {
          offset = 0;
        }
        else
        {
          offset -= signal_width;
          if ((offset + text_width) > w)
          {
            offset = w - text_width;
          }
        }
        gfx->setTextColor(color);
        gfx->setCursor(offset, ((height + 8) > graph_height) ? (graph_baseline - graph_height) : (graph_baseline - 10 - height));
        gfx->print(ssid);
        gfx->print('(');
        gfx->print(rssi);
        gfx->print(')');
        if (WiFi.encryptionType(i) == WIFI_AUTH_OPEN)
        {
          gfx->print('*');
        }
      }
    }
  }

  // draw 2.4 GHz graph base axle
  gfx->drawFastHLine(0, graph24_baseline, w, RGB565_WHITE);
  for (idx = 0; idx < 14; idx++)
  {
    channel = channel_legend[idx];
    offset = (idx + 2) * channel24_width;
    if (channel > 0)
    {
      gfx->setTextColor(channel_color[idx]);
      gfx->setCursor(offset - ((channel < 10) ? 3 : 6), graph24_baseline + 2);
      gfx->print(channel);
    }
    if (ap_count_list[idx] > 0)
    {
      gfx->setTextColor(RGB565_LIGHTGREY);
      gfx->setCursor(offset - ((ap_count_list[idx] < 10) ? 3 : 6), graph24_baseline + 8 + 2);
      gfx->print(ap_count_list[idx]);
    }
  }

  // draw 5 GHz graph base axle
  gfx->drawFastHLine(0, graph50_baseline, w, RGB565_WHITE);
  for (idx = 14; idx < sizeof(channel_legend); idx++)
  {
    channel = channel_legend[idx];
    offset = (idx - 14 + 4) * channel50_width;
    if (channel > 0)
    {
      gfx->setTextColor(channel_color[idx]);
      gfx->setCursor(offset - ((channel < 100) ? 6 : 9), graph50_baseline + 2);
      gfx->print(channel);
    }
    if (ap_count_list[idx] > 0)
    {
      gfx->setTextColor(RGB565_LIGHTGREY);
      gfx->setCursor(offset - ((ap_count_list[idx] < 10) ? 3 : 6), graph50_baseline + 8 + 2);
      gfx->print(ap_count_list[idx]);
    }
  }
  gfx->setTextColor(RGB565_MEDIUMBLUE, RGB565_BLACK);
  gfx->setCursor(w - 18, graph24_baseline + 8 + 2);
  gfx->printf("%03d", ap24_count);
  gfx->setTextColor(RGB565_LIMEGREEN, RGB565_BLACK);
  gfx->setCursor(w - 18, graph50_baseline + 8 + 2);
  gfx->printf("%03d", ap50_count);

  gfx->setTextSize(2);
  gfx->setTextColor(RGB565_WHITE, RGB565_MEDIUMBLUE);
  gfx->setCursor(0, graph24_baseline + 1);
  gfx->print("2.4");
  gfx->setTextColor(RGB565_WHITE, RGB565_LIMEGREEN);
  gfx->setCursor(0, graph50_baseline + 1);
  gfx->print("5");
  gfx->setTextSize(1);

#ifdef CANVAS
  gfx->flush();
#endif

  // Wait a bit before scanning again
  delay((scan_count < 2) ? 0 : SCAN_INTERVAL);
  ++scan_count;

#if defined(SCAN_COUNT_SLEEP)
  // POWER SAVING
  if (scan_count >= SCAN_COUNT_SLEEP)
  {
#if defined(LCD_PWR_PIN)
    pinMode(LCD_PWR_PIN, INPUT); // disable pin
#endif
#if defined(LCD_PWR_PIN1)
    pinMode(LCD_PWR_PIN1, INPUT); // disable pin
    pinMode(LCD_PWR_PIN2, INPUT); // disable pin
    pinMode(LCD_PWR_PIN3, INPUT); // disable pin
#endif

#if defined(GFX_BL)
    pinMode(GFX_BL, INPUT); // disable pin
#endif

    esp_deep_sleep_start();
  }
#endif // defined(SCAN_COUNT_SLEEP)
}

#endif // #if CONFIG_SOC_WIFI_SUPPORT_5G

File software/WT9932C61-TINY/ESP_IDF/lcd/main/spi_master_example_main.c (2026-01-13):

/* SPI Master example

   This example code is in the Public Domain (or CC0 licensed, at your option.)

   Unless required by applicable law or agreed to in writing, this
   software is distributed on an "AS IS" BASIS, WITHOUT WARRANTIES OR
   CONDITIONS OF ANY KIND, either express or implied.
*/
#include <stdio.h>
#include <stdlib.h>
#include <string.h>
#include <inttypes.h>
#include "freertos/FreeRTOS.h"
#include "freertos/task.h"
#include "esp_system.h"
#include "driver/spi_master.h"
#include "driver/gpio.h"

#include "pretty_effect.h"

/*
 This code displays some fancy graphics on the 320x240 LCD on an ESP-WROVER_KIT board.
 This example demonstrates the use of both spi_device_transmit as well as
 spi_device_queue_trans/spi_device_get_trans_result and pre-transmit callbacks.

 Some info about the ILI9341/ST7789V: It has an C/D line, which is connected to a GPIO here. It expects this
 line to be low for a command and high for data. We use a pre-transmit callback here to control that
 line: every transaction has as the user-definable argument the needed state of the D/C line and just
 before the transaction is sent, the callback will set this line to the correct state.
*/

//////////////////////////////////////////////////////////////////////////////////////////////////////////
////////////// Please update the following configuration according to your HardWare spec /////////////////
//////////////////////////////////////////////////////////////////////////////////////////////////////////
#define LCD_HOST    SPI2_HOST

#define PIN_NUM_MISO -1
#define PIN_NUM_MOSI 2
#define PIN_NUM_CLK  1
#define PIN_NUM_CS   3

#define PIN_NUM_DC   4
#define PIN_NUM_RST  5
#define PIN_NUM_BCKL 6

#define LCD_BK_LIGHT_ON_LEVEL   1

//To speed up transfers, every SPI transfer sends a bunch of lines. This define specifies how many. More means more memory use,
//but less overhead for setting up / finishing transfers. Make sure 240 is dividable by this.
#define PARALLEL_LINES 8

/*
 The LCD needs a bunch of command/argument values to be initialized. They are stored in this struct.
*/
typedef struct {
    uint8_t cmd;
    uint8_t data[16];
    uint8_t databytes; //No of data in data; bit 7 = delay after set; 0xFF = end of cmds.
} lcd_init_cmd_t;

typedef enum {
    LCD_TYPE_ILI = 1,
    LCD_TYPE_ST,
    LCD_TYPE_MAX,
} type_lcd_t;

//Place data into DRAM. Constant data gets placed into DROM by default, which is not accessible by DMA.
DRAM_ATTR static const lcd_init_cmd_t st_init_cmds[] = {
    /* Memory Data Access Control, MX=MV=1, MY=ML=MH=0, RGB=0 */
    {0x36, {(1 << 5) | (1 << 6)}, 1},
    /* Interface Pixel Format, 16bits/pixel for RGB/MCU interface */
    {0x3A, {0x55}, 1},
    /* Porch Setting */
    {0xB2, {0x0c, 0x0c, 0x00, 0x33, 0x33}, 5},
    /* Gate Control, Vgh=13.65V, Vgl=-10.43V */
    {0xB7, {0x45}, 1},
    /* VCOM Setting, VCOM=1.175V */
    {0xBB, {0x2B}, 1},
    /* LCM Control, XOR: BGR, MX, MH */
    {0xC0, {0x2C}, 1},
    /* VDV and VRH Command Enable, enable=1 */
    {0xC2, {0x01, 0xff}, 2},
    /* VRH Set, Vap=4.4+... */
    {0xC3, {0x11}, 1},
    /* VDV Set, VDV=0 */
    {0xC4, {0x20}, 1},
    /* Frame Rate Control, 60Hz, inversion=0 */
    {0xC6, {0x0f}, 1},
    /* Power Control 1, AVDD=6.8V, AVCL=-4.8V, VDDS=2.3V */
    {0xD0, {0xA4, 0xA1}, 2},
    /* Positive Voltage Gamma Control */
    {0xE0, {0xD0, 0x00, 0x05, 0x0E, 0x15, 0x0D, 0x37, 0x43, 0x47, 0x09, 0x15, 0x12, 0x16, 0x19}, 14},
    /* Negative Voltage Gamma Control */
    {0xE1, {0xD0, 0x00, 0x05, 0x0D, 0x0C, 0x06, 0x2D, 0x44, 0x40, 0x0E, 0x1C, 0x18, 0x16, 0x19}, 14},
    /* Sleep Out */
    {0x11, {0}, 0x80},
    /* Display On */
    {0x29, {0}, 0x80},
    {0, {0}, 0xff}
};

DRAM_ATTR static const lcd_init_cmd_t ili_init_cmds[] = {
    /* Power control B, power control = 0, DC_ENA = 1 */
    {0xCF, {0x00, 0x83, 0X30}, 3},
    /* Power on sequence control,
     * cp1 keeps 1 frame, 1st frame enable
     * vcl = 0, ddvdh=3, vgh=1, vgl=2
     * DDVDH_ENH=1
     */
    {0xED, {0x64, 0x03, 0X12, 0X81}, 4},
    /* Driver timing control A,
     * non-overlap=default +1
     * EQ=default - 1, CR=default
     * pre-charge=default - 1
     */
    {0xE8, {0x85, 0x01, 0x79}, 3},
    /* Power control A, Vcore=1.6V, DDVDH=5.6V */
    {0xCB, {0x39, 0x2C, 0x00, 0x34, 0x02}, 5},
    /* Pump ratio control, DDVDH=2xVCl */
    {0xF7, {0x20}, 1},
    /* Driver timing control, all=0 unit */
    {0xEA, {0x00, 0x00}, 2},
    /* Power control 1, GVDD=4.75V */
    {0xC0, {0x26}, 1},
    /* Power control 2, DDVDH=VCl*2, VGH=VCl*7, VGL=-VCl*3 */
    {0xC1, {0x11}, 1},
    /* VCOM control 1, VCOMH=4.025V, VCOML=-0.950V */
    {0xC5, {0x35, 0x3E}, 2},
    /* VCOM control 2, VCOMH=VMH-2, VCOML=VML-2 */
    {0xC7, {0xBE}, 1},
    /* Memory access control, MX=MY=0, MV=1, ML=0, BGR=1, MH=0 */
    {0x36, {0x28}, 1},
    /* Pixel format, 16bits/pixel for RGB/MCU interface */
    {0x3A, {0x55}, 1},
    /* Frame rate control, f=fosc, 70Hz fps */
    {0xB1, {0x00, 0x1B}, 2},
    /* Enable 3G, disabled */
    {0xF2, {0x08}, 1},
    /* Gamma set, curve 1 */
    {0x26, {0x01}, 1},
    /* Positive gamma correction */
    {0xE0, {0x1F, 0x1A, 0x18, 0x0A, 0x0F, 0x06, 0x45, 0X87, 0x32, 0x0A, 0x07, 0x02, 0x07, 0x05, 0x00}, 15},
    /* Negative gamma correction */
    {0XE1, {0x00, 0x25, 0x27, 0x05, 0x10, 0x09, 0x3A, 0x78, 0x4D, 0x05, 0x18, 0x0D, 0x38, 0x3A, 0x1F}, 15},
    /* Column address set, SC=0, EC=0xEF */
    {0x2A, {0x00, 0x00, 0x00, 0xEF}, 4},
    /* Page address set, SP=0, EP=0x013F */
    {0x2B, {0x00, 0x00, 0x01, 0x3f}, 4},
    /* Memory write */
    {0x2C, {0}, 0},
    /* Entry mode set, Low vol detect disabled, normal display */
    {0xB7, {0x07}, 1},
    /* Display function control */
    {0xB6, {0x0A, 0x82, 0x27, 0x00}, 4},
    /* Sleep out */
    {0x11, {0}, 0x80},
    /* Display on */
    {0x29, {0}, 0x80},
    {0, {0}, 0xff},
};

/* Send a command to the LCD. Uses spi_device_polling_transmit, which waits
 * until the transfer is complete.
 *
 * Since command transactions are usually small, they are handled in polling
 * mode for higher speed. The overhead of interrupt transactions is more than
 * just waiting for the transaction to complete.
 */
void lcd_cmd(spi_device_handle_t spi, const uint8_t cmd, bool keep_cs_active)
{
    esp_err_t ret;
    spi_transaction_t t;
    memset(&t, 0, sizeof(t));       //Zero out the transaction
    t.length = 8;                   //Command is 8 bits
    t.tx_buffer = &cmd;             //The data is the cmd itself
    t.user = (void*)0;              //D/C needs to be set to 0
    if (keep_cs_active) {
        t.flags = SPI_TRANS_CS_KEEP_ACTIVE;   //Keep CS active after data transfer
    }
    ret = spi_device_polling_transmit(spi, &t); //Transmit!
    assert(ret == ESP_OK);          //Should have had no issues.
}
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

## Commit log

2025-12-09 🎉 init: 首次更新
    [BOM_WT9932C2-TINY_V1.0.xlsx, BOM_WT9932C3-TINY_V1.0.xlsx, BOM_WT9932C5-TINY_V1.0.xlsx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]
2025-12-10 🐞 fix: 修改贴纸错误
2025-12-10 🐞 fix: 修改C5贴纸错误
2025-12-10 🐞 fix: 更新贴纸源工程
2025-12-10 ✨ feat: 增加lcd例程
2026-01-13 🐞 fix: 修改C61的例程引脚
2026-02-12 🐞 fix: 修改更新C61资料
2026-02-12 ✨ feat: 增加C5 wifi分析仪
